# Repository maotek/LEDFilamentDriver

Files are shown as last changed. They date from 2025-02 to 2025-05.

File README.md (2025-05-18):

## LED Filament Driver

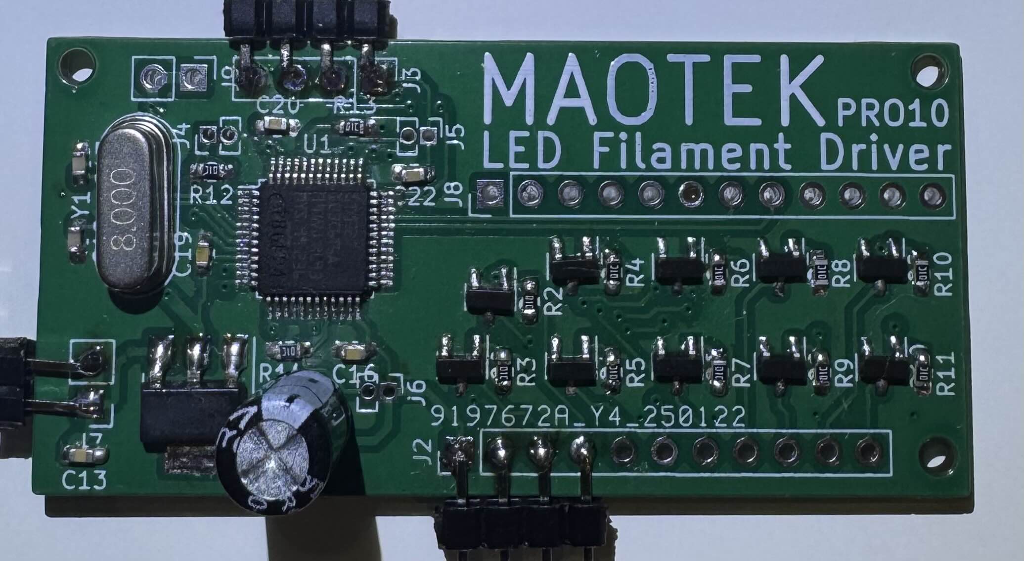
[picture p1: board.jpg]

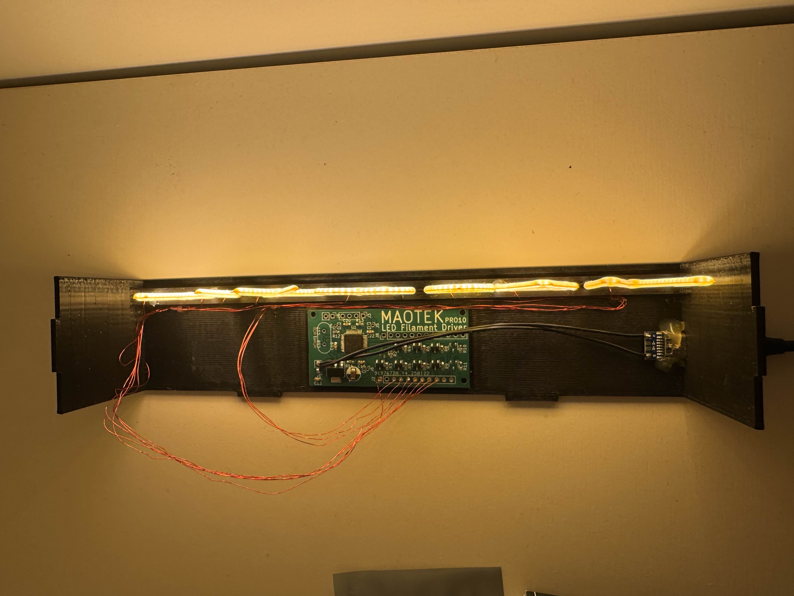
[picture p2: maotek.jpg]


---

## Remarks

- KiCad project also contains a driver for EDP displays, however this schematic was not included in the final production PCB.
- Produced by JLCPCB.
- Crystal is not necessary for application not requiring precise timing.

---
## Issues

- Unfortunately, output 9 and 10 do not have PWM output. Will be fixed in the next revisions if any.
- AMS1117 3.3 is rated for 1A, make sure the LED filaments do no consume more than 1A. Otherwise they will overheat.
- For loads higher than 1A, consider buck converters.

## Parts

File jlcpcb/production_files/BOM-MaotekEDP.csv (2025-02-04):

Comment | Designator | Footprint | LCSC
Q_NMOS_GSD | Q1 | SOT-23-3
Conn_01x02 | J7 | PinHeader_1x02_P2.54mm_Vertical
8MHz | Y1 | Crystal_HC18-U_Vertical
AMS1117-3.3 | U2 | SOT-223-3_TabPin2
STM32F103C8Tx | U1 | LQFP-48_7x7mm_P0.5mm
10K | R14 | R_0603_1608Metric_Pad0.98x0.95mm_HandSolder
10K | R13 | R_0603_1608Metric_Pad0.98x0.95mm_HandSolder
10K | R12 | R_0603_1608Metric_Pad0.98x0.95mm_HandSolder
10K | R11 | R_0603_1608Metric_Pad0.98x0.95mm_HandSolder
10K | R10 | R_0603_1608Metric_Pad0.98x0.95mm_HandSolder
10K | R9 | R_0603_1608Metric_Pad0.98x0.95mm_HandSolder
10K | R8 | R_0603_1608Metric_Pad0.98x0.95mm_HandSolder
10K | R7 | R_0603_1608Metric_Pad0.98x0.95mm_HandSolder
10K | R6 | R_0603_1608Metric_Pad0.98x0.95mm_HandSolder
10K | R5 | R_0603_1608Metric_Pad0.98x0.95mm_HandSolder
10K | R4 | R_0603_1608Metric_Pad0.98x0.95mm_HandSolder
10K | R3 | R_0603_1608Metric_Pad0.98x0.95mm_HandSolder
10K | R2 | R_0603_1608Metric_Pad0.98x0.95mm_HandSolder
Q_NMOS_GSD | Q10 | SOT-23-3
Q_NMOS_GSD | Q9 | SOT-23-3
Q_NMOS_GSD | Q8 | SOT-23-3
Q_NMOS_GSD | Q7 | SOT-23-3
Q_NMOS_GSD | Q6 | SOT-23-3
Q_NMOS_GSD | Q5 | SOT-23-3
Q_NMOS_GSD | Q4 | SOT-23-3
Q_NMOS_GSD | Q3 | SOT-23-3
Q_NMOS_GSD | Q2 | SOT-23-3
Conn_01x02 | J6 | PinHeader_1x02_P1.27mm_Vertical
Conn_01x02 | J5 | PinHeader_1x02_P1.27mm_Vertical
Conn_01x02 | J4 | PinHeader_1x02_P1.27mm_Vertical
Conn_01x04 | J3 | PinHeader_1x04_P2.54mm_Vertical
Conn_01x11 | J2 | PinHeader_1x11_P2.54mm_Vertical
100nF | C22 | R_0603_1608Metric_Pad0.98x0.95mm_HandSolder
100nF | C20 | R_0603_1608Metric_Pad0.98x0.95mm_HandSolder
100nF | C19 | R_0603_1608Metric_Pad0.98x0.95mm_HandSolder
20p | C18 | C_0603_1608Metric_Pad1.08x0.95mm_HandSolder
20p | C17 | C_0603_1608Metric_Pad1.08x0.95mm_HandSolder
100nF | C16 | C_0603_1608Metric_Pad1.08x0.95mm_HandSolder
470uF | C14 | CP_Radial_D5.0mm_P2.50mm
100nF | C13 | C_0603_1608Metric_Pad1.08x0.95mm_HandSolder
Conn_01x02 | J9 | PinHeader_1x02_P2.54mm_Vertical
Conn_01x12 | J8 | PinHeader_1x12_P2.54mm_Vertical

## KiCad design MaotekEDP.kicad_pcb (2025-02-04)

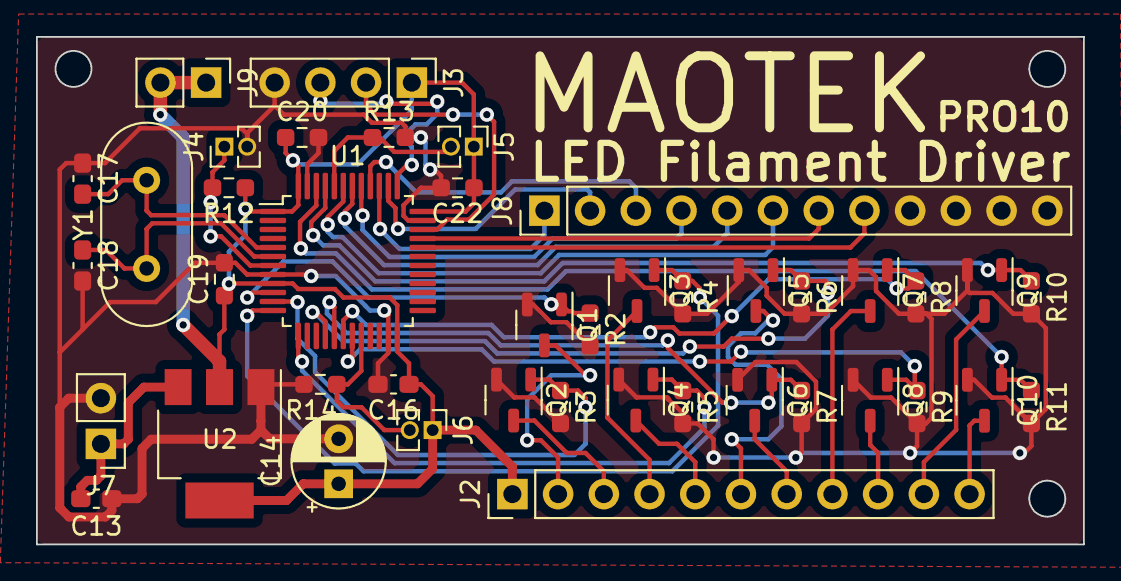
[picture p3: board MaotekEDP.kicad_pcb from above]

Board: 2 copper layers, 58.2 x 28.2 mm, 42 parts (0 on the bottom side), 38 nets.

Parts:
C13, C16: 100nF; C_0603_1608Metric_Pad1.08x0.95mm_HandSolder
C14: 470uF; CP_Radial_D5.0mm_P2.50mm
C17, C18: 20p; C_0603_1608Metric_Pad1.08x0.95mm_HandSolder
C19, C20, C22: 100nF; R_0603_1608Metric_Pad0.98x0.95mm_HandSolder
J2: Conn_01x11; PinHeader_1x11_P2.54mm_Vertical
J3: Conn_01x04; PinHeader_1x04_P2.54mm_Vertical
J4, J5, J6: Conn_01x02; PinHeader_1x02_P1.27mm_Vertical
J7, J9: Conn_01x02; PinHeader_1x02_P2.54mm_Vertical
J8: Conn_01x12; PinHeader_1x12_P2.54mm_Vertical
Q1, Q2, Q3, Q4, Q5, Q6, Q7, Q8, Q9, Q10: Q_NMOS_GSD; SOT-23-3
R2, R3, R4, R5, R6, R7, R8, R9, R10, R11, R12, R13, R14: 10K; R_0603_1608Metric_Pad0.98x0.95mm_HandSolder
U1: STM32F103C8Tx; LQFP-48_7x7mm_P0.5mm
U2: AMS1117-3.3; SOT-223-3_TabPin2
Y1: 8MHz; Crystal_HC18-U_Vertical

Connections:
32: J8.8, U1.32 (PA11)
33: J8.7, U1.33 (PA12)
38: J8.2, U1.38 (PA15)
39: J8.1, U1.39 (PB3)
40: J8.3, U1.40 (PB4)
41: J8.4, U1.41 (PB5)
42: J8.5, U1.42 (PB6)
43: J8.6, U1.43 (PB7)
+3.3V: C14.1, C16.1, C19.1, C20.1, C22.1, J2.1, J3.1, J5.1, J6.1, J9.1, J9.2, R12.1, U1.1 (VBAT), U1.9 (VDDA), U1.24 (VDD), U1.36 (VDD), U1.48 (VDD), U2.2 (VO)
+5V: C13.1, J7.1, U2.3 (VI)
BOOT0: J5.2, R13.1, U1.44 (BOOT0)
BOOT1: J6.2, R14.1, U1.20 (PB2)
GND: C13.2, C14.2, C16.2, C17.1, C18.2, C19.2, C20.2, C22.2, J3.4, J4.2, J7.2, J8.9, J8.10, J8.11, J8.12, Q1.2 (S), Q2.2 (S), Q3.2 (S), Q4.2 (S), Q5.2 (S), Q6.2 (S), Q7.2 (S), Q8.2 (S), Q9.2 (S), Q10.2 (S), R2.2, R3.2, R4.2, R5.2, R6.2, R7.2, R8.2, R9.2, R10.2, R11.2, R13.2, R14.2, U1.8 (VSSA), U1.23 (VSS), U1.35 (VSS), U1.47 (VSS), U2.1 (GND)
NRST: J4.1, R12.2, U1.7 (NRST)
OSCIN: C17.2, U1.5 (PD0), Y1.2
OSCOUT: C18.1, U1.6 (PD1), Y1.1
SWCLK: J3.3, U1.37 (PA14)
SWIO: J3.2, U1.34 (PA13)
in1: Q1.1 (G), R2.1, U1.10 (PA0)
in2: Q2.1 (G), R3.1, U1.11 (PA1)
in3: Q3.1 (G), R4.1, U1.12 (PA2)
in4: Q4.1 (G), R5.1, U1.13 (PA3)
in5: Q5.1 (G), R6.1, U1.16 (PA6)
in6: Q6.1 (G), R7.1, U1.17 (PA7)
in7: Q7.1 (G), R8.1, U1.18 (PB0)
in8: Q8.1 (G), R9.1, U1.19 (PB1)
in9: Q9.1 (G), R10.1, U1.45 (PB8)
in10: Q10.1 (G), R11.1, U1.46 (PB9)
out1: J2.2, Q1.3 (D)
out2: J2.3, Q2.3 (D)
out3: J2.4, Q3.3 (D)
out4: J2.5, Q4.3 (D)
out5: J2.6, Q5.3 (D)
out6: J2.7, Q6.3 (D)
out7: J2.8, Q7.3 (D)
out8: J2.9, Q8.3 (D)
out9: J2.10, Q9.3 (D)
out10: J2.11, Q10.3 (D)
